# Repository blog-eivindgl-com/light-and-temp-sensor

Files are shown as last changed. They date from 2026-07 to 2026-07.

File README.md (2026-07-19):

# An ESP32 light and temp/humidity sensor module for Home Assistant
A simple project using ESP32 to report light sensor, temperature and humidity data over MQTT to Home Assistant.

## Home assistant dashboard
The Home Assistant dashboard for this sensor could look something like this:
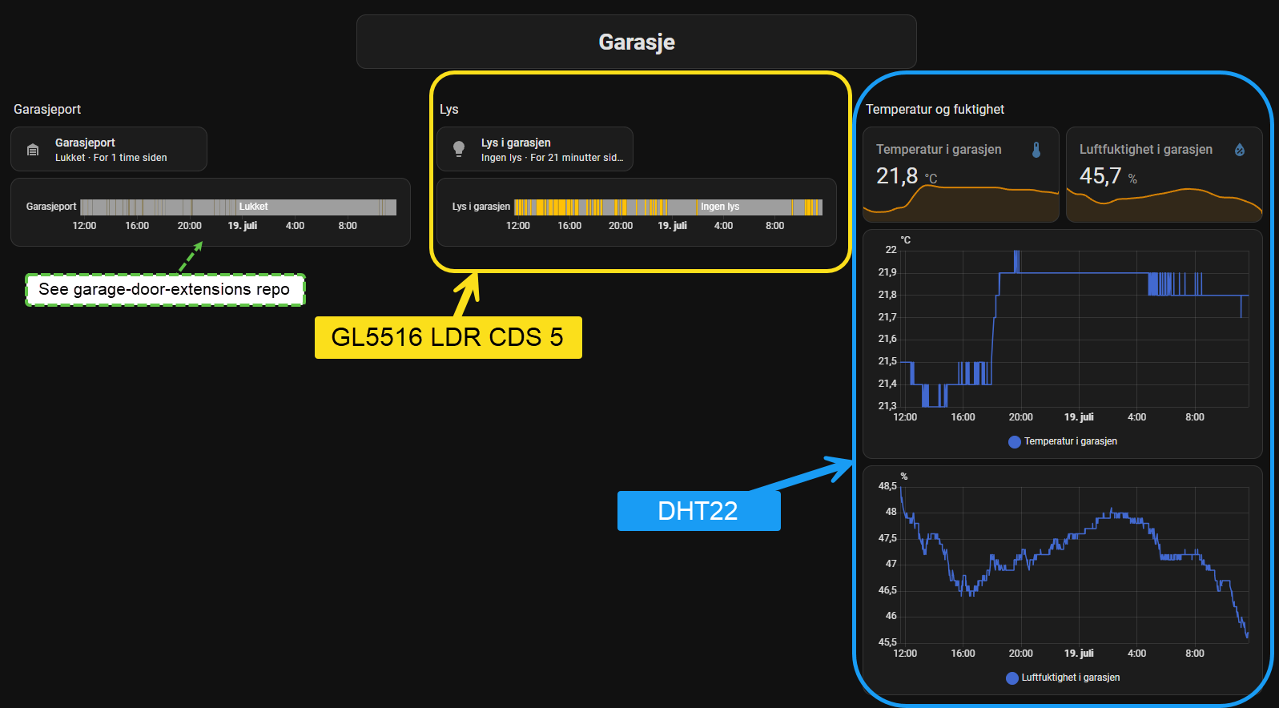
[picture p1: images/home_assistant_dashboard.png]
Home Assistant


This dashboard also includes sensor data from the garage door, provided by another project: https://github.com/blog-eivindgl-com/garage-door-extensions

## Component list
 - [ESP32 WROOM dev board](https://www.aliexpress.com/item/1005005655238798.html) (or similar)
 - [GL5516 LDR CDS 5 light sensor](https://www.aliexpress.com/item/1005007522318459.html)
 - [DHT22 temperature and humidity sensor](https://www.aliexpress.com/item/1005007188553339.html)
 - [10kΩ resistors](https://www.aliexpress.com/item/1005011772534173.html)
 - [Perf board](https://www.aliexpress.com/item/1005001704591847.html)
 - [18awg solid core wires](https://www.temu.com/no-en/18-20-22-24-awg-wire-solid-core--wire-6-different-colored-breadboard-wires-18-24gauge-electronic-wire-with-pvc-for--g-605656169989220.html)
 - Flexible signal cables between the ESP32 and the perf board
 - Power cables from an external power source
 - 2mm acrylic transparent plate cut into a 8mm x 35mm pice
 - 5 M3 screws for attaching the lid to the box
 - Fire resistant filament for 3D printed housing

## Electronics
Prototyping sketch for wiring components:
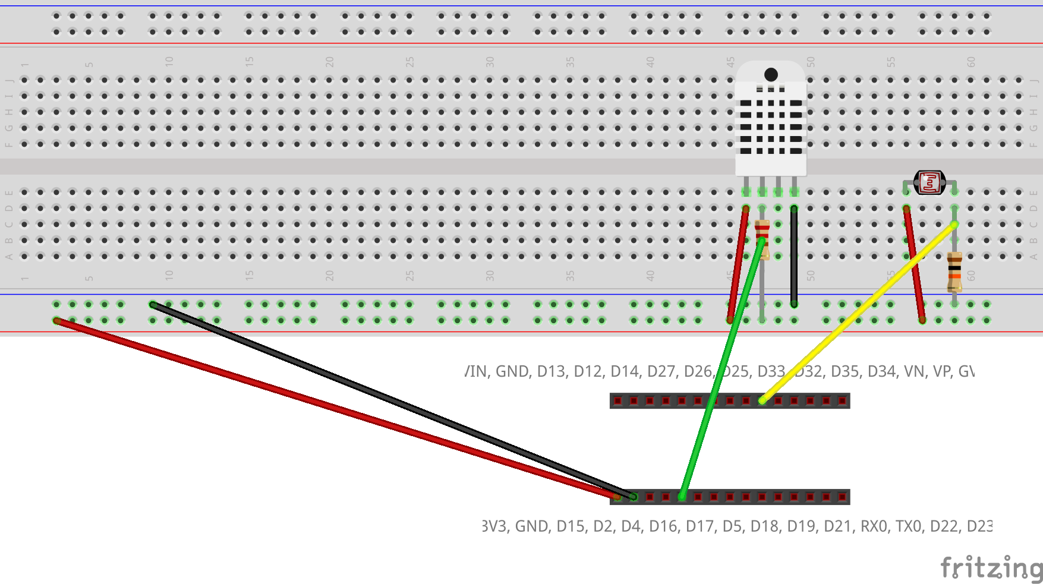
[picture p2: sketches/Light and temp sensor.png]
prototyping


Refer to [this spreadsheet](https://github.com/user-attachments/files/29973649/Temp-light.soldering.sketch.ods) which documents soldering the same connections on a perf board. That also includes screw terminals for 5V DC power cables from an external source and flexible wires between the perf board and the ESB32 dev board.

The 3D model gives a visual clue on how to arrange the components on the perf board:
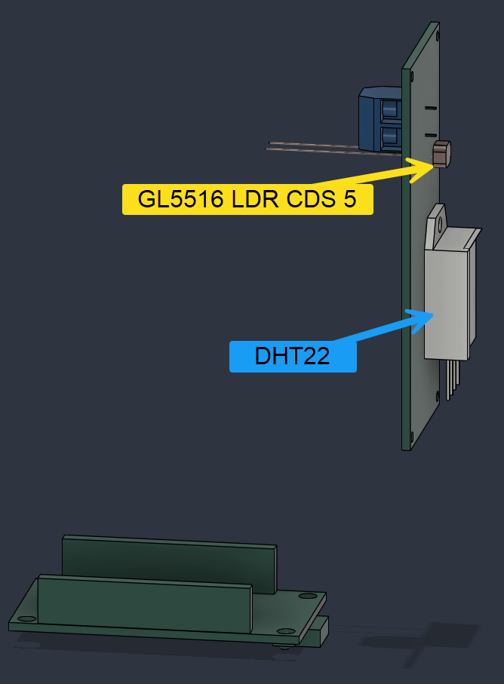
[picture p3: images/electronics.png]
electronics


## Source code
The esp32_light_and_temp_sensor_module.ino file contains C++ code which can be used with Arduino IDE to upload the program to the dev board.

It requires a local parameters.h file, which contains secrets for the local environment like WiFi password and MQTT broker parameters. Use the following template:
```
#ifndef GARAGELIGHT_PARAMETERS_H
#define GARAGELIGHT_PARAMETERS_H

// Secrets
const char *wifi_ssid = "<your-wifi-ssid>"; 
const char *wifi_password = "<your-wifi-password>";

const char *mqttServer = "<your-mqtt-broker-ip-or-dns>";
const char *mqtt_user = "<your-mqtt-broker-username>";
const char *mqtt_password = "<your-mqtt-broker-password>";

// Other environment parameters
const char *ntpServer1 = "<local-time-server-or-some-external-time-server>";
const char *ntpServer2 = "time.nist.gov";
const long gmtOffset_sec = 3600;
const int daylightOffset_sec = 3600;
const char *time_zone = "CET-1CEST,M3.5.0,M10.5.0/3";  // TimeZone rule for Europe/Rome including daylight adjustment rules (optional)

#endif
```

### Reqired libraries
 - [PubSubClient](http://pubsubclient.knolleary.net/) for MQTT messages
 - [WiFi library for Arduino](https://github.com/arduino-libraries/WiFi)
 - [DHT sensor library](https://github.com/adafruit/DHT-sensor-library)

## 3D printed case
 A box wrapping the electronics. Perf board with sensors is located at the right side of the box, using an acrylic window for the light sensor, and providing a cutout for the DHT22 sensor. ESP32 board is located upside down on the bottom side of the box. 
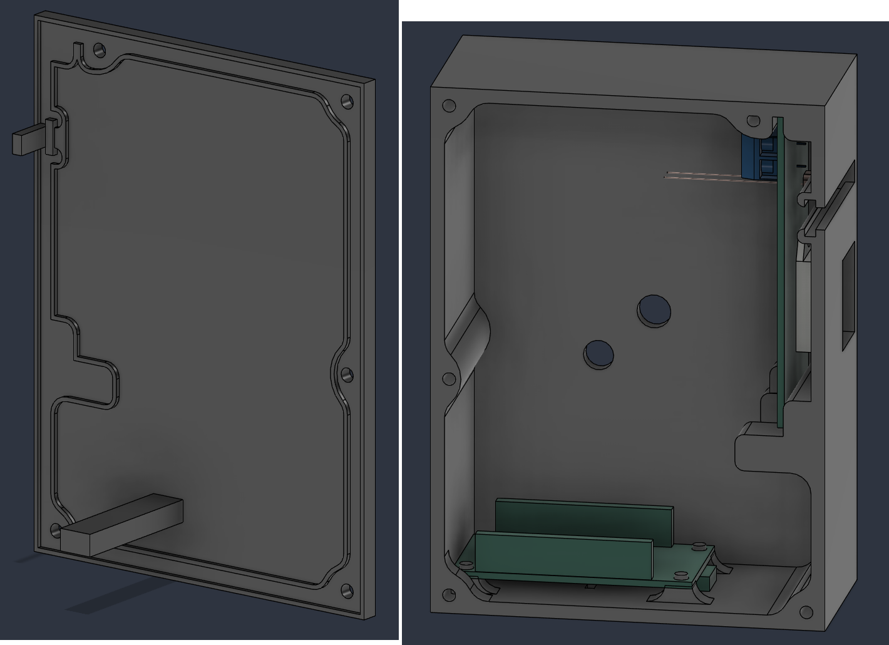
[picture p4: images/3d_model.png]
3D model


The box has cutouts for the two onboard LEDs and push buttons of a standard ESP32-WROOM-32 dev board, giving access to the reset button using a toothpicker.

 The backside of the box has cutouts for an Ethernet cable, but only two wires are used to provide power from a 5V DC source. There's also a hole for the Multibuild Tbolt used to mount the box to a [Multibuild tile](https://docs.multibuild.io/beginner-section/core-parts-documentation#1-multiboard-tile) on a standard small thread hole. I used the [Bolt Generator](https://multibuild.io/tools/bolt-generator-pro) to create a custom Tbolt with small threads, 11mm length with a Small Flat head:
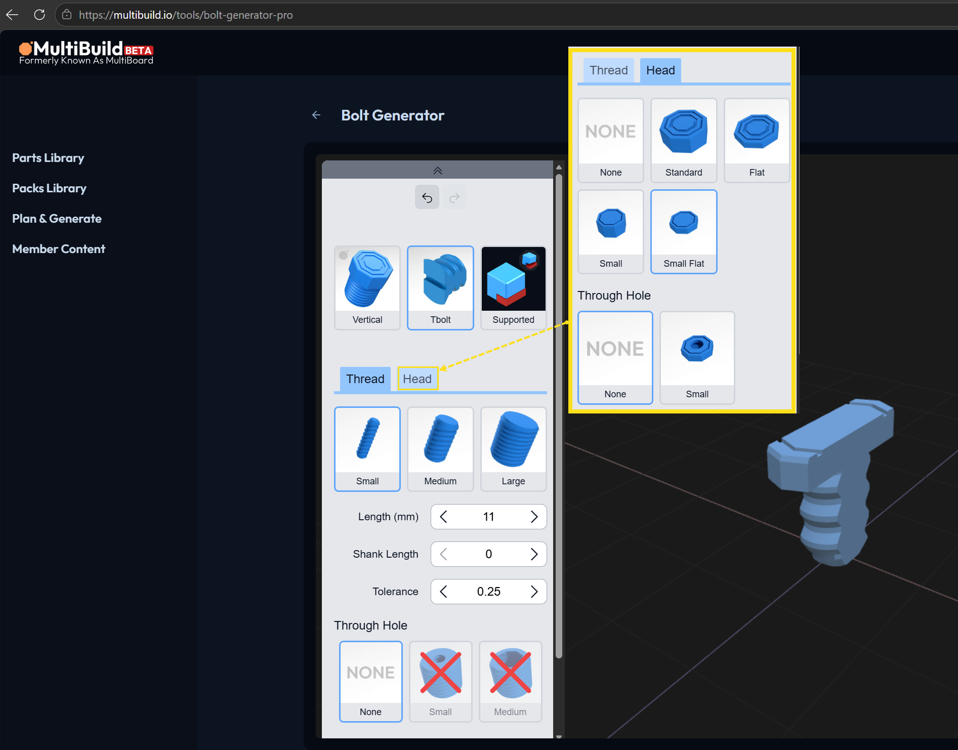
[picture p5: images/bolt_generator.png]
Bolt Generator
 

Feel free to mount this in a much simpler way. I just like Multibuild's flexibilty instead of drilling holes in the wall for every project I make.

Use fire resistant filament when 3D printing housing for electronics. Picture of the complete box mounted to a Multibuild tile:
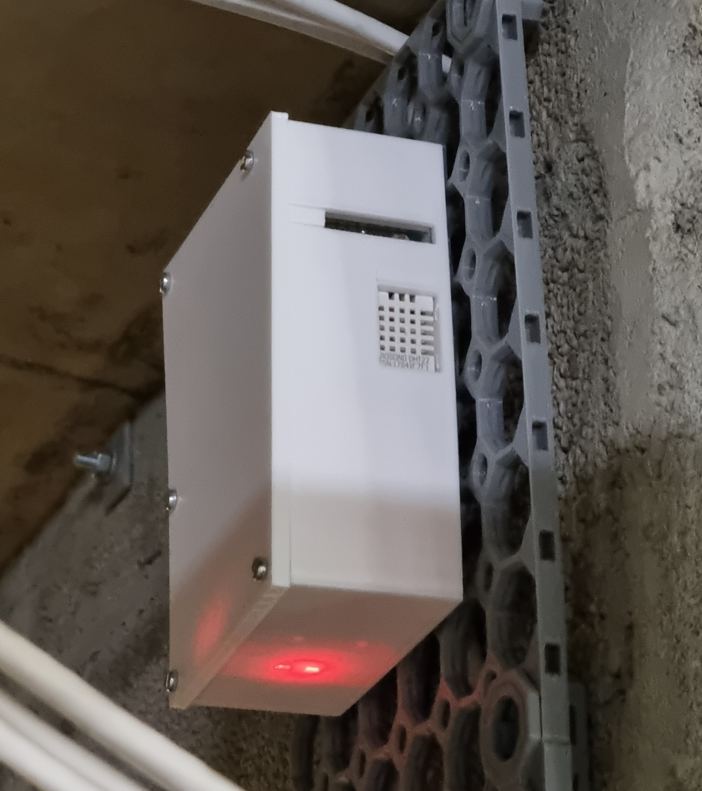
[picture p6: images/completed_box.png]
Completed box


Step files for the box and lid are provided in the 3d_model folder together with the Fusion360 f3d file, which should give you several options to modify the model to your needs. There's also a 3mf file for the slicer program. The 3D model files are also shared on [Printables](https://www.printables.com/model/1785509-esp32-light-and-temperaturehumidity-project-for-ho).

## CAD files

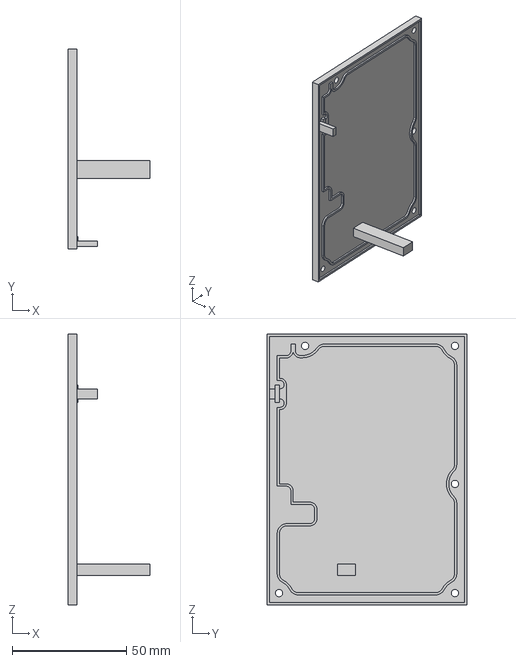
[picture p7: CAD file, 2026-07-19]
3d_model/Lid.step
36.0 x 87.3 x 118.5 mm

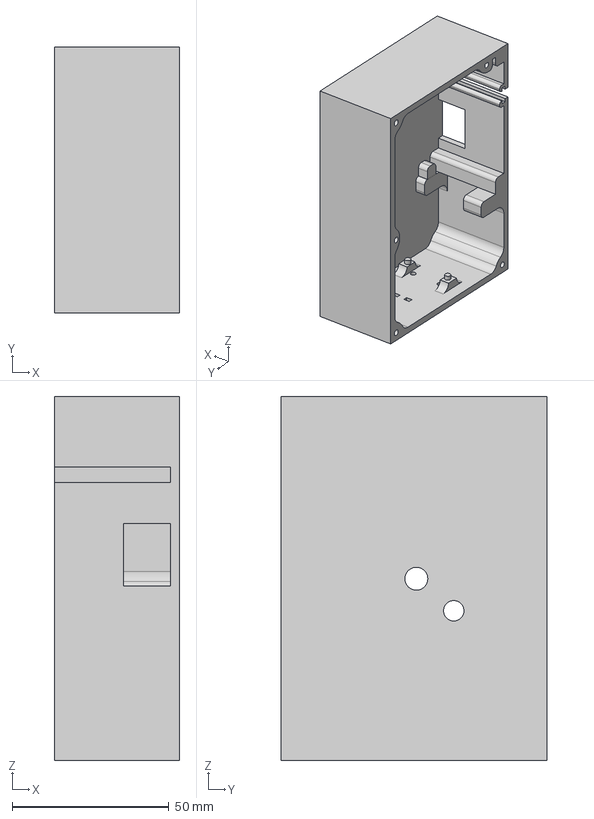
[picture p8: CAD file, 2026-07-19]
3d_model/Light and Temp sensor box.step
40.0 x 84.9 x 116.1 mm

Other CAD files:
3d_model/Light and Temp sensor box.3mf
3d_model/Light and Temp sensor v1.f3d

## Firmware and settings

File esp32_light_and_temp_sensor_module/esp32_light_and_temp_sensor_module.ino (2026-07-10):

#include <WiFi.h>
#include <PubSubClient.h>
#include <DHT.h>
#include <atomic>
#include "time.h"
#include "esp_sntp.h"
#include "parameters.h"

const int LedPin = 2;
unsigned long ledOnTime = 0;

const int LightSensorPin = 32;
const int LightSensorThreashold = 500;

int lightSensorValue = 0;
int previousLightSensorValue = 0;
char lightSensorState[4] = "off";
std::atomic<bool> lightSensorStateChanged = false;
unsigned long lightSensorChangedTime = 0;

const int DhtPin = 4;
const unsigned long DhtCheckInterval = 30000;  // DHT22 needs >=2s between reads; 30s is plenty for HA graphs
DHT dht(DhtPin, DHT22);

float temperatureValue = NAN;
float humidityValue = NAN;

WiFiClient wifiClient;
PubSubClient mqttClient(wifiClient);  // MQTT

void checkLightSensorState() {
  lightSensorValue = analogRead(LightSensorPin);
  if (std::abs(lightSensorValue - previousLightSensorValue) >= 50) {
    Serial.printf("LightSensorValue is %d\n", lightSensorValue);
    previousLightSensorValue = lightSensorValue;

    if (lightSensorValue > LightSensorThreashold) {
      // Light is ON, check if we need to update state
      // Capture change if previous state was off, and that state was captured at least 1s ago
      if (strcmp(lightSensorState, "off") == 0 && (millis() - lightSensorChangedTime) >= 1000) {
        strncpy(lightSensorState, "on", 4);
        lightSensorStateChanged = true;
        lightSensorChangedTime = millis();
      }
    } else {
      // Light is OFF, check if we need to update state
      // Capture change if previous state was on, and that state was captured at least 1s ago
      if (strcmp(lightSensorState, "on") == 0 && (millis() - lightSensorChangedTime) >= 1000) {
        strncpy(lightSensorState, "off", 4);
        lightSensorStateChanged = true;
        lightSensorChangedTime = millis();
      }
    }
  }

  // Report new state if it has actually changed
  if (lightSensorStateChanged && strcmp(lightSensorState, "on") == 0) {
    Serial.println("Light is on");
    // Message for ESP32 display module
    mqttClient.publish("garageLight/lightStateChanged", "on");
    // Message for Home Assitant
    mqttClient.publish("garage/light/sensor", "ON");
    lightSensorStateChanged = false;
    // Turn on LED to indicate message published
    turnOnLed();
  } else if (lightSensorStateChanged && strcmp(lightSensorState, "off") == 0) {
    Serial.println("Light is off");
    // Message for ESP32 display module
    mqttClient.publish("garageLight/lightStateChanged", "off");
    // Message for Home Assitant
    mqttClient.publish("garage/light/sensor", "OFF");
    lightSensorStateChanged = false;
    // Turn on LED to indicate message published
    turnOnLed();
  }
}

void checkTempHumidity() {
  float newTemperature = dht.readTemperature();
  float newHumidity = dht.readHumidity();

  if (isnan(newTemperature) || isnan(newHumidity)) {
    Serial.println("Failed to read from DHT22 sensor!");
    return;
  }

  temperatureValue = newTemperature;
  humidityValue = newHumidity;
  Serial.printf("Temperature: %.1f C, Humidity: %.1f %%\n", temperatureValue, humidityValue);

  char payload[8];
  dtostrf(temperatureValue, 4, 1, payload);
  mqttClient.publish("garage/temperature/sensor", payload);

  dtostrf(humidityValue, 4, 1, payload);
  mqttClient.publish("garage/humidity/sensor", payload);

  // Turn on LED to indicate message published
  turnOnLed();
}

void ensureMqttBrokerConnected() {
  // Reconnect if not connected
  if (!mqttClient.connected()) {
    Serial.printf("Connecting to %s...\n", mqttServer);
    
    // Attempt to connect
    if (mqttClient.connect("GarageLightSensor", mqtt_user, mqtt_password)) {
      Serial.printf("connected to %s\n", mqttServer);
      // Subscribe to topics
      mqttClient.subscribe("garageLight/queryDeviceStatus");
    } else {
      Serial.print("failed, rc=");
      Serial.print(mqttClient.state());
      Serial.println();
    }
  }
}

void turnOnLed() {
  // Turn the indicator LED on and record time to automatically turn it off again after a while
  digitalWrite(LedPin, HIGH);
  ledOnTime = millis();
}

void turnOffLed() {
  digitalWrite(LedPin, LOW);
}

void ensureWifiConnected() {
  if (WiFi.status() != WL_CONNECTED) { 
    Serial.println("WiFi disconnected! Reconnecting..."); 
    WiFi.disconnect(); 
    WiFi.begin(wifi_ssid, wifi_password); 
    unsigned long startAttemptTime = millis();
    
    // Try for up to 10 seconds 
    while (WiFi.status() != WL_CONNECTED && millis() - startAttemptTime < 10000) { 
      delay(250); 
      Serial.print("."); 
    } 
    
    if (WiFi.status() == WL_CONNECTED) { 
      Serial.println("WiFi reconnected"); 
    } else { 
      Serial.println("WiFi reconnect failed"); 
    } 
  }
}

void printLocalTime() {
  struct tm timeinfo;
  if (!getLocalTime(&timeinfo)) {
    Serial.println("No time available (yet)");
    return;
  }
  Serial.println(&timeinfo, "%A, %B %d %Y %H:%M:%S");
}

// Callback function (gets called when time adjusts via NTP)
void timeavailable(struct timeval *t) {
  Serial.println("Got time adjustment from NTP!");
  printLocalTime();
}

void incomingMqttMessage(char *topic, uint8_t *message, unsigned int length) {
  Serial.print("Message received on topic: ");
  Serial.println(topic);

  Serial.print("Message: ");

  String value = "";

  for (int i = 0; i < length; i++) {
    Serial.print((char)message[i]);
    value += (char)message[i];
  }

  Serial.println();

  if (strcmp(topic, "garageLight/queryDeviceStatus") == 0) {
    // Send current state of garage light sensor
    if (digitalRead(LightSensorPin) == HIGH) {
      strncpy(lightSensorState, "on", 4);
      lightSensorStateChanged = true;
    } else {
      strncpy(lightSensorState, "off", 4);
      lightSensorStateChanged = true;
    }
  }
}

void publishDiscoveryMqttMessage() {
  String lightSensorDiscoveryMessage = "{"
    "\"name\": \"Garage Light\","
    "\"unique_id\": \"garage_light_sensor\","
    "\"state_topic\": \"garage/light/sensor\","
    "\"payload_on\": \"ON\","
    "\"payload_off\": \"OFF\","
    "\"device_class\": \"light\","
    "\"icon\": \"mdi:garage\""
  "}";
  Serial.println("Publishing Home Assistant Binary Sensor Discovery Message");
  mqttClient.publish("homeassistant/binary_sensor/garage_light_sensor/config", lightSensorDiscoveryMessage.c_str(), true); // true means the message is retained when HA is restarted
}

void publishTemperatureDiscoveryMqttMessage() {
  String temperatureDiscoveryMessage = "{"
    "\"name\": \"Garage Temperature\","
    "\"unique_id\": \"garage_temperature_sensor\","
    "\"state_topic\": \"garage/temperature/sensor\","
    "\"unit_of_measurement\": \"°C\","
    "\"device_class\": \"temperature\","
    "\"state_class\": \"measurement\","
    "\"icon\": \"mdi:thermometer\""
  "}";
  Serial.println("Publishing Home Assistant Temperature Sensor Discovery Message");
  mqttClient.publish("homeassistant/sensor/garage_temperature_sensor/config", temperatureDiscoveryMessage.c_str(), true);
}

void publishHumidityDiscoveryMqttMessage() {
  String humidityDiscoveryMessage = "{"
    "\"name\": \"Garage Humidity\","
    "\"unique_id\": \"garage_humidity_sensor\","
    "\"state_topic\": \"garage/humidity/sensor\","
    "\"unit_of_measurement\": \"%\","
    "\"device_class\": \"humidity\","
    "\"state_class\": \"measurement\","
    "\"icon\": \"mdi:water-percent\""
  "}";
  Serial.println("Publishing Home Assistant Humidity Sensor Discovery Message");
  mqttClient.publish("homeassistant/sensor/garage_humidity_sensor/config", humidityDiscoveryMessage.c_str(), true);
}

void subscribeToMqttTopics() {
  if (mqttClient.subscribe("garageLight/queryDeviceStatus")) {
    Serial.println("Subscribed to topic: garageLight/queryDeviceStatus");
  } else {
    Serial.println("Failed to subscribe to topic!");
  }
}

void setup() {
  Serial.begin(115200);

  // Turn on LED until setup is successfully executed
  pinMode(LedPin, OUTPUT);
  digitalWrite(LedPin, HIGH);
  
  dht.begin();

  // First step is to configure WiFi STA and connect in order to get the current time and date.
  Serial.printf("Connecting to %s ", wifi_ssid);
  WiFi.begin(wifi_ssid, wifi_password);

  /**
   * NTP server address could be acquired via DHCP,
   *
   * NOTE: This call should be made BEFORE esp32 acquires IP address via DHCP,
   * otherwise SNTP option 42 would be rejected by default.
   * NOTE: configTime() function call if made AFTER DHCP-client run
   * will OVERRIDE acquired NTP server address
   */
  esp_sntp_servermode_dhcp(1);  // (optional)

  while (WiFi.status() != WL_CONNECTED) {
    delay(500);
    Serial.print(".");
  }
  Serial.println(" CONNECTED");

  // set notification call-back function
  sntp_set_time_sync_notification_cb(timeavailable);

  /**
   * This will set configured ntp servers and constant TimeZone/daylightOffset
   * should be OK if your time zone does not need to adjust daylightOffset twice a year,
   * in such a case time adjustment won't be handled automagically.
   */
  configTime(gmtOffset_sec, daylightOffset_sec, ntpServer1, ntpServer2);

  /**
   * A more convenient approach to handle TimeZones with daylightOffset
   * would be to specify a environment variable with TimeZone definition including daylight adjustmnet rules.
   * A list of rules for your zone could be obtained from https://github.com/esp8266/Arduino/blob/master/cores/esp8266/TZ.h
   */
  //configTzTime(time_zone, ntpServer1, ntpServer2);

  // Connect to MQTT broker
  mqttClient.setServer(mqttServer, 1883);
  mqttClient.setCallback(incomingMqttMessage);
  mqttClient.setBufferSize(512);  // default 256 bytes is too small for the sensor discovery payloads

  // Connect to MQTT broker
  mqttClient.setServer(mqttServer, 1883);
  mqttClient.setCallback(incomingMqttMessage);

  while (!mqttClient.connected()) {
    ensureWifiConnected();
    ensureMqttBrokerConnected();
  }

  if (mqttClient.connected()) {
    // Register this device as a sensor for the emergency stop button in Home Assistant
    publishDiscoveryMqttMessage();
    publishTemperatureDiscoveryMqttMessage();
    publishHumidityDiscoveryMqttMessage();
  } else {
    Serial.println("MQTT not connected - cannot publish discovery message");
  }

  // Turn off LED to indicate setup completed
  digitalWrite(LedPin, LOW);
}

void loop() {
  static unsigned long lastCheckedLightState = 0;
  static unsigned long lastCheckedDht = 0;

  if (millis() - ledOnTime >= 1000) {
    turnOffLed();
  }

  // Reconnect both WiFi and MQTT if connection is broken
  ensureWifiConnected();
  ensureMqttBrokerConnected();

  mqttClient.loop(); // Process incoming MQTT messages

  // Handle light state
  if (millis() - lastCheckedLightState >= 100) {
    checkLightSensorState();
    lastCheckedLightState = millis();  // Reset timing
  }

  // Handle temperature/humidity
  if (millis() - lastCheckedDht >= DhtCheckInterval) {
    checkTempHumidity();
    lastCheckedDht = millis();  // Reset timing
  }
}

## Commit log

2026-07-08 Issue #1 - Add light sensor
    [esp32_light_and_temp_sensor_module.ino]
2026-07-08 Claude solves issue #2
    [esp32_light_and_temp_sensor_module.ino]
2026-07-10 Issue #5 - LED indicator
    [esp32_light_and_temp_sensor_module.ino]
2026-07-10 Issue #6 - Add sketch
    [Light and temp sensor.fzz]
2026-07-19 Add 3D models for box
    [Lid.step, Light and Temp sensor box.3mf, Light and Temp sensor box.step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]
2026-07-19 Update README with Printables link for 3D models
    Added a link to the 3D model files on Printables.
